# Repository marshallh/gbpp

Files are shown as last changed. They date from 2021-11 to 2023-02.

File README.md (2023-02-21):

# gbpp
 Replacement power regulator for Game Boy Pocket.
 
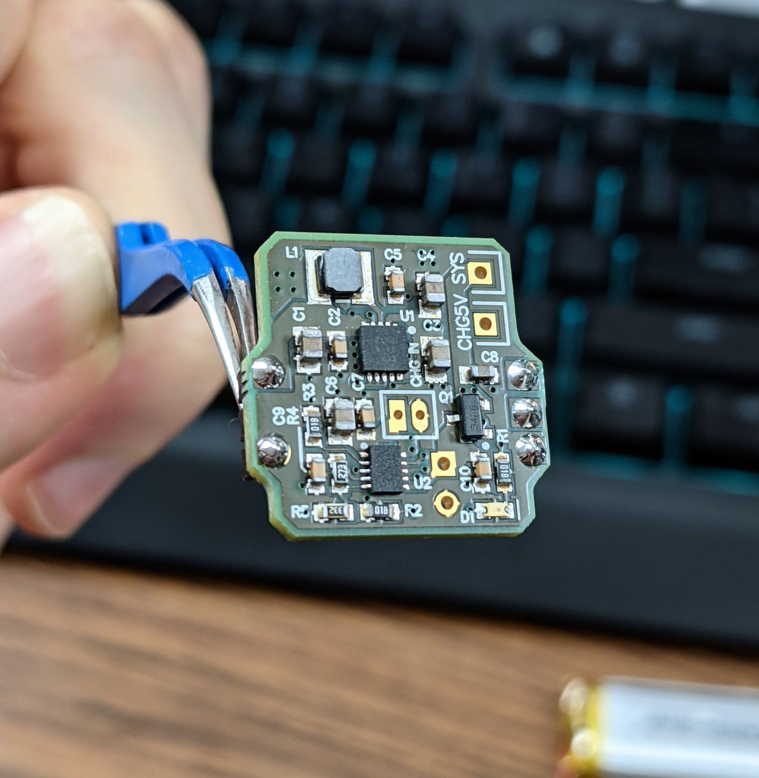
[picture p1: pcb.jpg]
isn't it beautiful
 

 The GBP famously cannot handle running many flash carts reliably. And if you add an IPS mod, it probably won't even boot.
 Now if you use this board, you can run anything you want all at once, and even from a lipo cell.
 
 * Lithium ion cell charge & play support (charge rate: 256mA)
 * Wire up to a 5V source, such as USB-C to charge the battery
 * Charging LED - shuts off when charging is complete
 * Running off original AAA also works but may not handle IPS mods or EZ-Flash because the alkaline cells cannot supply enough current
 * Removes LCD Vee supply, so IPS mod is necessary (or make your own -18V regulator)

Please use the zipped gerbers, and buy parts from the BOM. I strongly recommend using a reflow oven to build this, QFNs require it. Hot air may be possible but dicey. Do not try this as your first soldering project.

## Assembly:

1. Use a paste stencil from OSHStencils or a very thin steel stencil. Use leadfree paste and only apply in 1 pass for sharpest transfer
2. Place all parts. Make sure U1 and U2 are not swapped, and pin 1 is correct.
3. Reflow up to 230-250C.
4. Solder in two 3-pin male pin headers, one with the middle pin removed via pliers.
5. Solder wires to battery and/or 5v charge source (external USB-C port), and solder a wire to connect SYS to the Pocket power input. Do this now as it gets harder once the pcb is soldered in place.
6. Install the pinned PCB into the Gameboy Pocket PCB.

## Net names:
CHG5V: Solder your 5v source from a USB port here. If you don't know how to wire a USB-C port, refer to the internet. Present on both the front and back of the pcb for easy access.

VBAT+: Lipo battery pos terminal (NOT the AAA battery contacts on the pocket)

VBAT-: Lipo battery neg terminal

SYS: Solder to the power input on the gameboy. The fuse near the headphone jack is the best place to wire this. It should be the same net as the pocket's battery pos terminal.

Note that this board does not provide intrinsic lipo protection. However, almost all cells available already have a BMS board preinstalled.

## Optional 5V regulator only (no charging)
If you only need a 5V regulator, and intend to use the original alkaline cells without any charging circuitry, then you may omit the bottom half of the PCB. The parts to leave off are

C6 C7 C8 C9 C10 R1 R2 R3 R4 R5 U2 D1

It will no longer be necessary to add any wires, such as CHG5V or SYS. 

## Board Preview

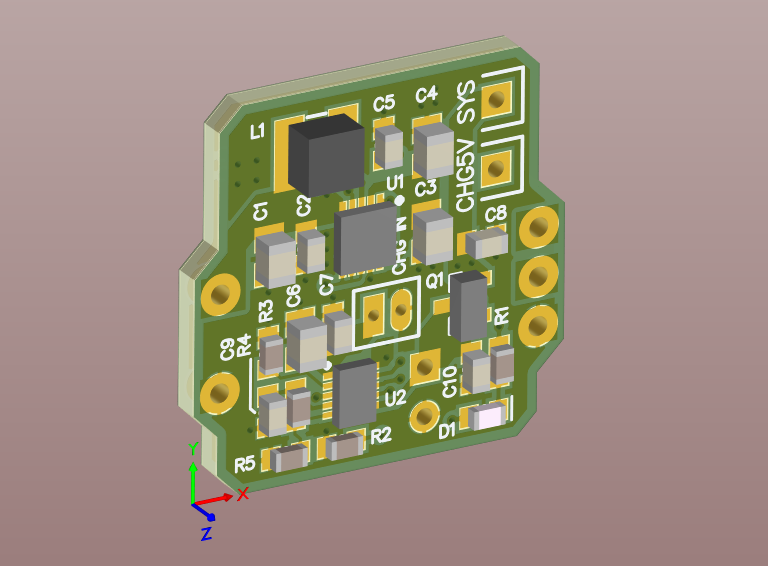
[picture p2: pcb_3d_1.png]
front view

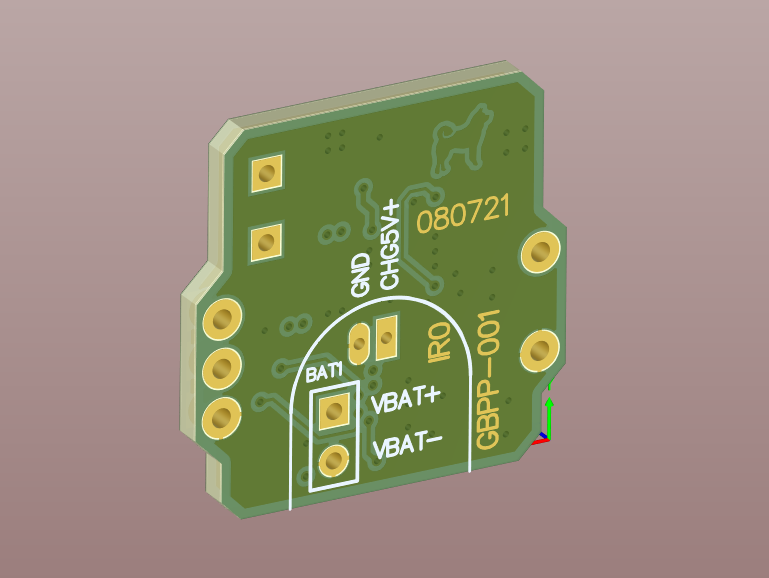
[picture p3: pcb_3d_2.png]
back view

 
 ## Troubleshooting:
 
When in doubt, consult the original GBP schematic, and look at the schematic of this board.
 
I recommend trimming the plastic on the pin headers if the pcb is too close to the pocket plastic shell.

Here it is installed in the Pocket Color I built
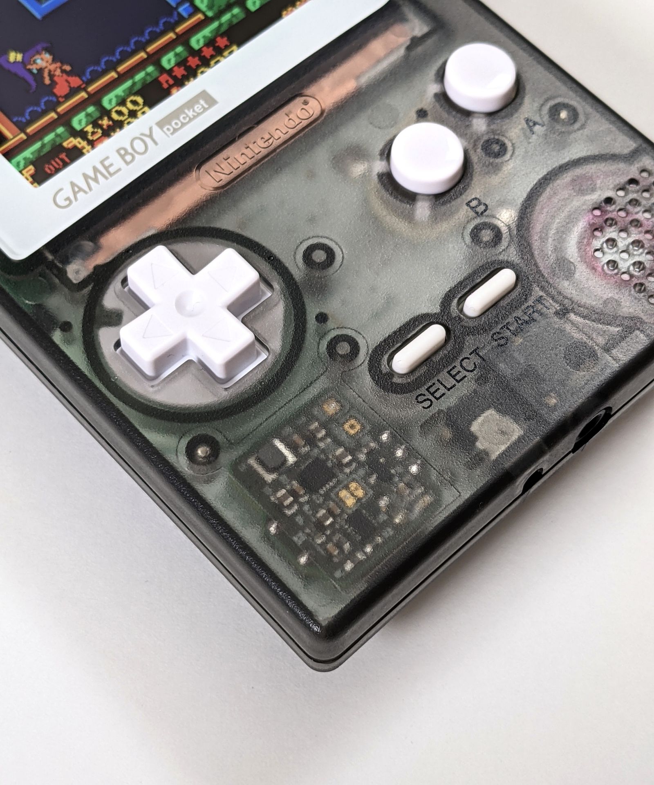
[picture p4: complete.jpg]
hotness 1

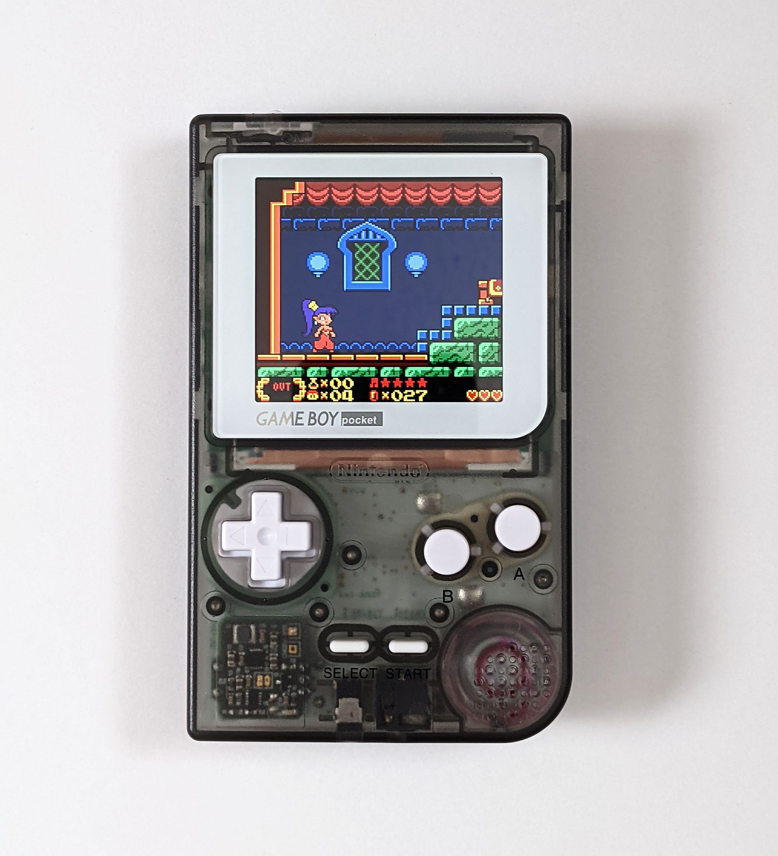
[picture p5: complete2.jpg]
hotness 2


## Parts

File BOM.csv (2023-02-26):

Comment | Description | Designator | Footprint | LibRef | Quantity
10uF | Capacitor Ceramic | C1, C3, C4, C6 | CAPC0805(2012)130_N | CAP | 4
0.1uF | Capacitor Ceramic | C2, C5, C7, C9, C10 | CAPC0603(1608)100_N | CAP | 5
1uF | Capacitor Ceramic | C8 | CAPC0603(1608)100_N | CAP | 1
RED LED | LED OPTO | D1 | LED_0603 | LED | 1
2.2uH NR3015T2R2M | Power Inductor SMD | L1 | IND_3x3_SMD | IND_PWR | 1
Header 3 | Header, 3-Pin | P1, P2 | HDR1X3 | Header 3 | 2
FDN342P | P CHANNEL FET | Q1 | SOT-23 | TRANSISTOR PCH FET | 1
1k | Resistor SMD | R1, R2, R3 | RESC0603(1608)_N | RES | 3
27k | Resistor SMD | R4 | RESC0603(1608)_N | RES | 1
3.3k | Resistor SMD | R5 | RESC0603(1608)_N | RES | 1
TPS61202 | Buck-Boost Regulator | U1 | DRC10_TI | TPS61202 | 1
BQ25050DQCR | IC BATT CHG LI-ION 1CELL 10WSON | U2 | TI_WSON10 | bq25050 | 1

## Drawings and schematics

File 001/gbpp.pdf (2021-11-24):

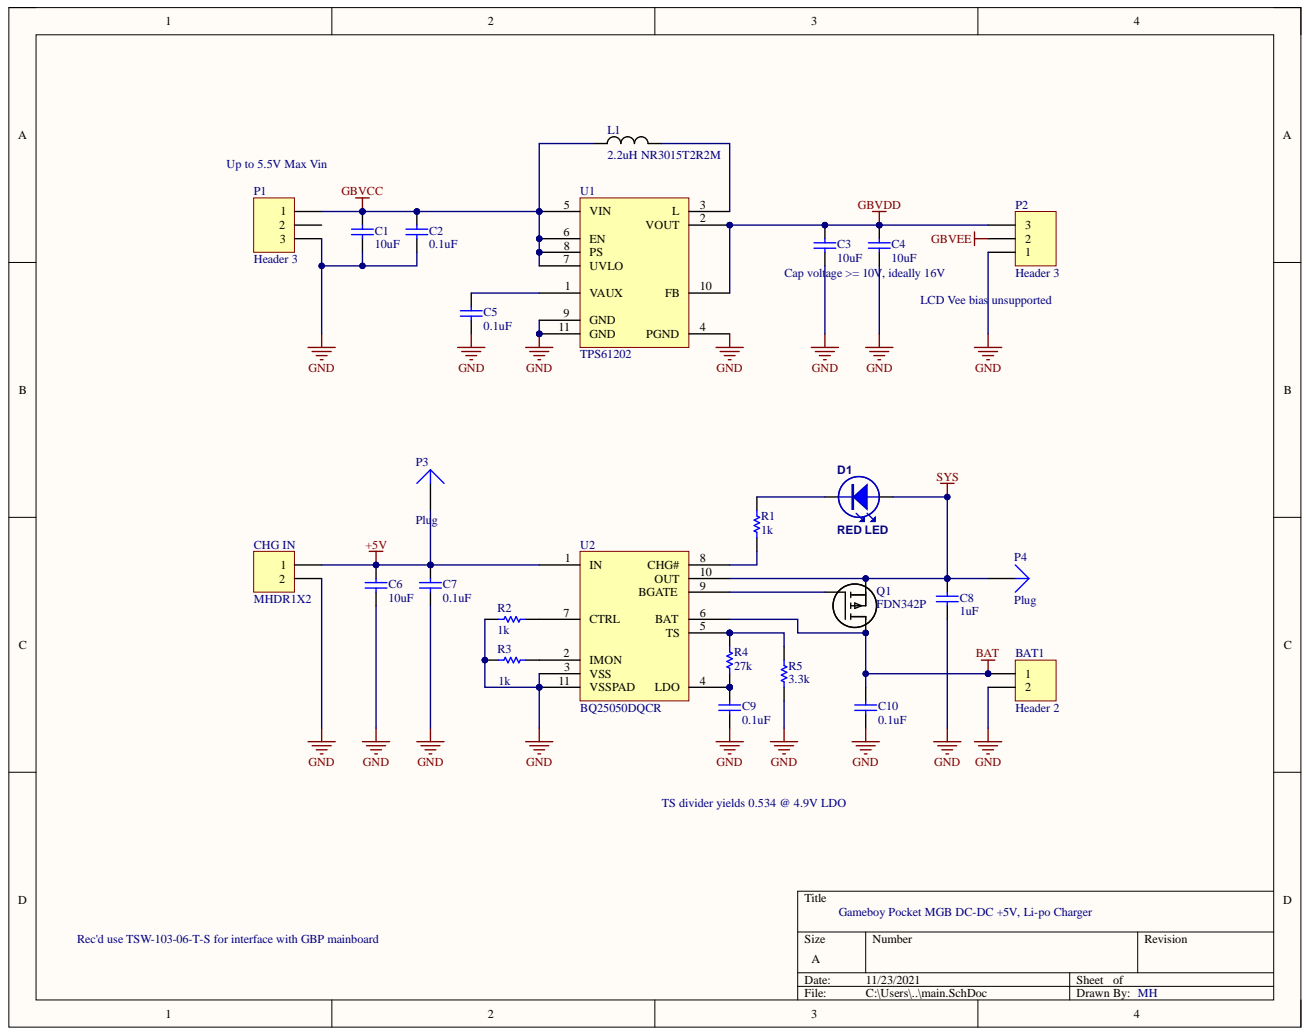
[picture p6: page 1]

Up to 5.5V Max Vin

TS divider yields 0.534 @ 4.9V LDO

Gameboy Pocket MGB DC-DC +5V, Li-po Charger

Rec'd use TSW-103-06-T-S for interface with GBP mainboard

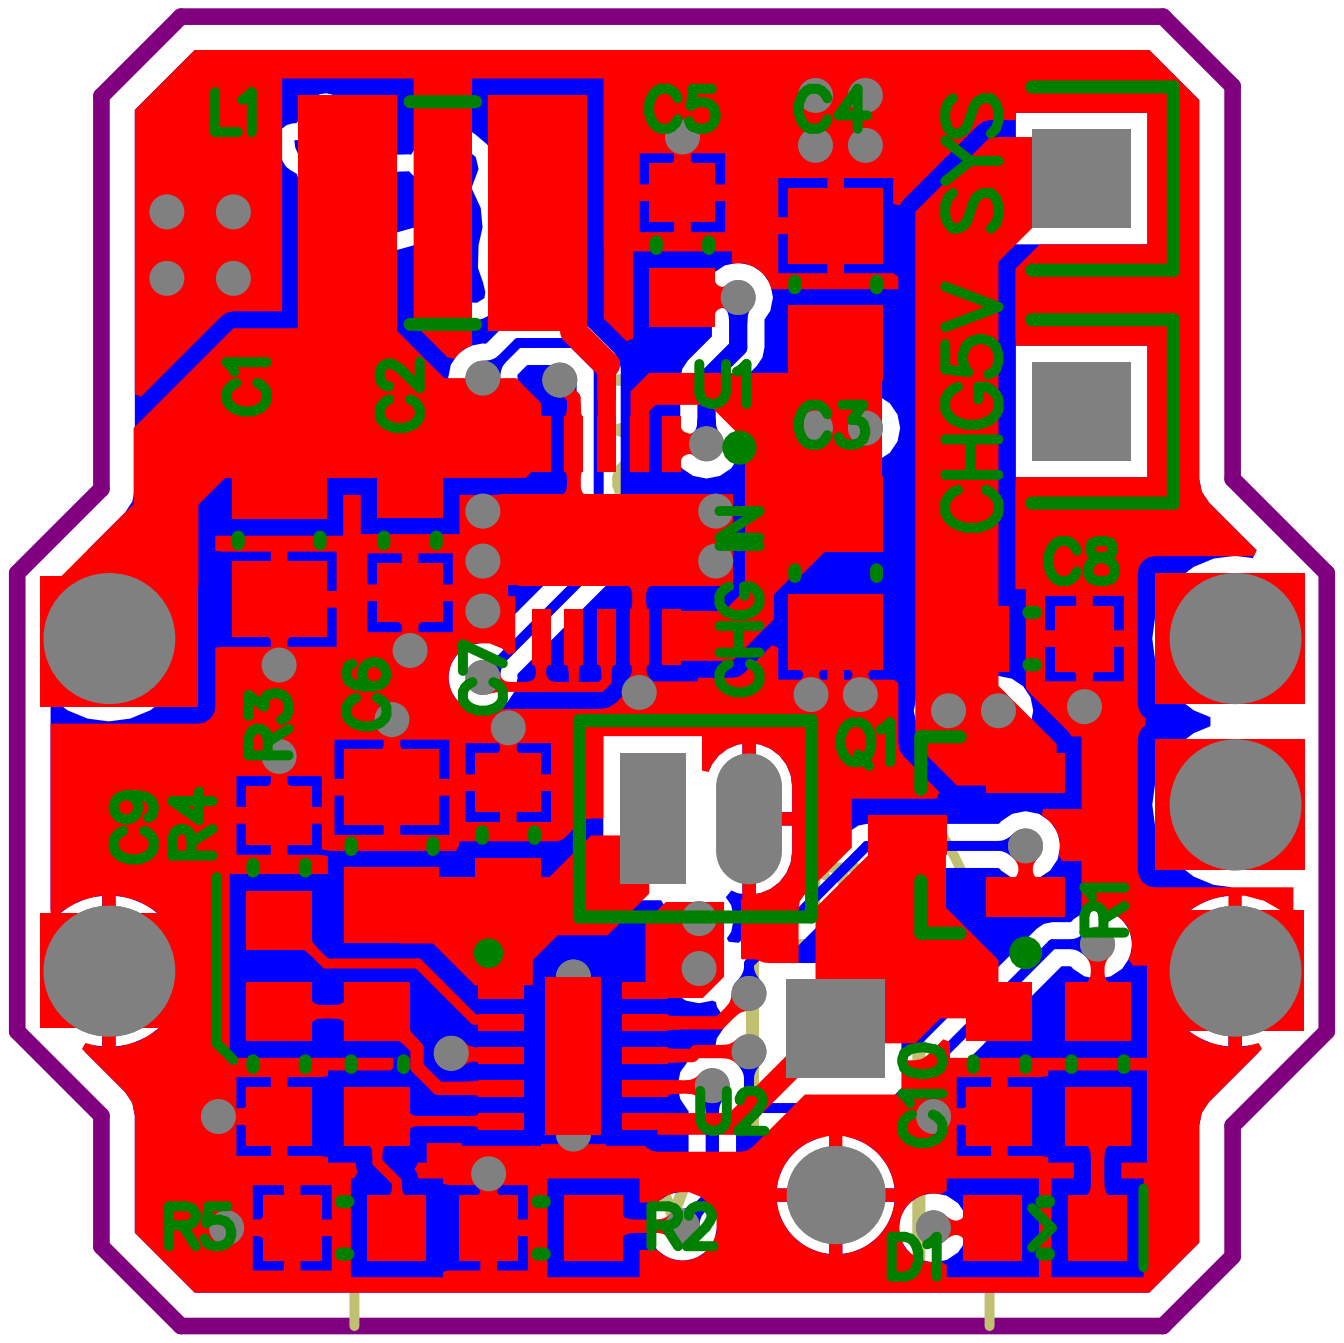
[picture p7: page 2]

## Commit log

2021-11-24 add pcb image
2022-02-27 BOM as CSV
    [BOM.csv]
